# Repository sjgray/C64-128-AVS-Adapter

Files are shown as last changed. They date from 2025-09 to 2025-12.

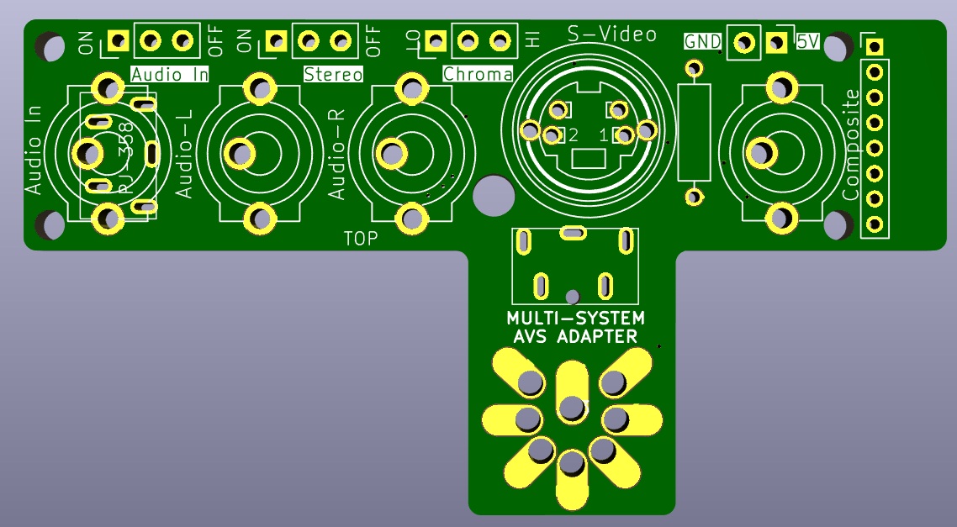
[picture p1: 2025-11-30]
V2/Pics/Render-front.jpg

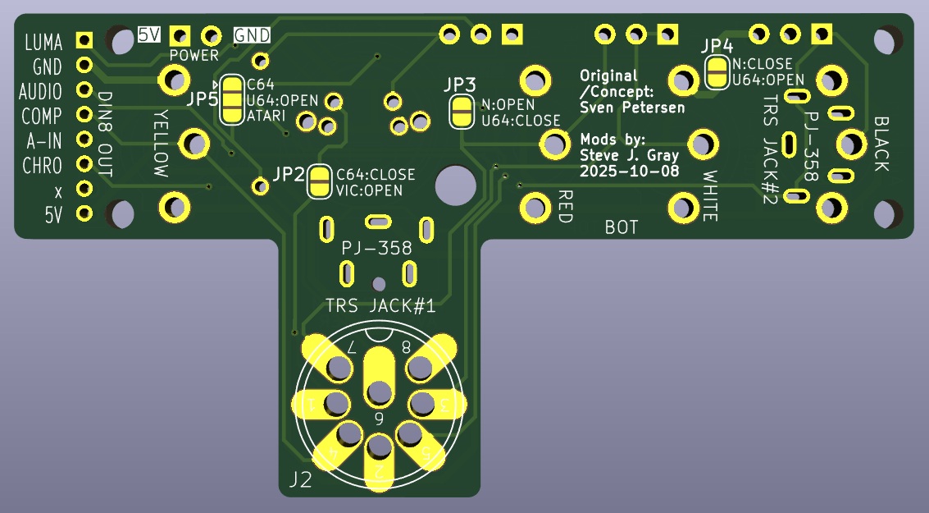
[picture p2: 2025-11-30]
V2/Pics/Render-back.jpg

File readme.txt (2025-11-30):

C64/C128 and Multi-System AVS Boards  by Steve J. Gray,  WWW.CBMSTEVE.CA
====================================

These are Commodore C64/C128 and Multi-System adapter boards based on
designs by Sven Petersen (https://github.com/svenpetersen1965?tab=repositories)
Sven has several designs for C64, C128 and VIC-20. These are separate boards
due to different DIN connectors, placement, and pinout differences. Also the
boards were designed with Eagle CAD.

My idea was first to combine the C64 and C128 boards into one by re-arranging
the RCA and S-VIDEO connectors to place them all at the top and hence allowing
the board to work on either machine. This is my "C64/C128" version.

The second idea was to make a board that could be configurable for different
systems. I added various solder-pad jumpers and added VIC-20, VIC-20 S-Video,
and Atari 8-bit configurations. This is the "Multi-System AVS" version.

Since I use Kicad I initially imported Sven's designs to get the proper part
footprints, and then working from there pretty much re-designed everything
for the new form factor(s) and options. I also added options for TRS connector
jacks for the Audio In, a connector for power output, and PH2.0 connector for
an additional video link cable to my C128 VGA15kHz+S-VIDEO 40/80 adapter
board (coming soon).

Designs
=======

V1:	- "C64/C128 AVS", for late model C64, 64C, C128, C16, SX-64 etc with DIN-8 video port.
	- Relocated connectors.
	- Power connector for +5V.
	- Made all jumpers 3-pin for headers or small switches (2.54mm spacing).
	- Not suitable for 3D printed case due to clearance issue.
	- Verified working.

V2:	- Now "Multi-System AVS".
	- Add support for VIC-20 (DIN-5)
	- Add support VIC-20 with Retro-Channel S-video adapter board (DIN-5).
	- Add support for Atari 8-bit (DIN-5) and chroma output.
	- Add support for U64 (DIN-8).
	- Move switches to top for easier access.
	- Add more clearance above DIN connector. Good for 3D case (Future).
	- Add TRS jacks for audio in.
	- Add header for cable to my C128 video adapter board.
	- Verified working.

GitHub
======

Designs are available here: https://github.com/sjgray/C64-128-AVS-Adapter

History
=======

2025-09-13 - Created C64/C128-AVS adapter
2025-09-22 - Created Github
2025-10-08 - Created Multi-System AVS completed
2025-11-29 - Tested ok, released V2 to Github

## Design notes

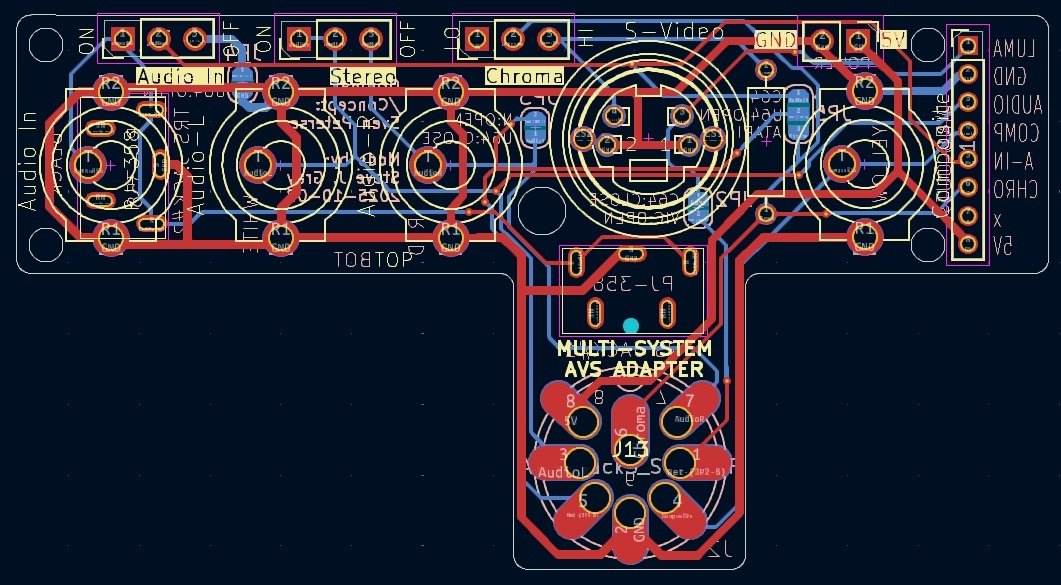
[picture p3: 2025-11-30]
V2/Pics/Routing.jpg

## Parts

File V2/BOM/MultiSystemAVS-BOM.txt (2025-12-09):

Multi-System AVS Adapter board - BOM
====================================

Mini Switches angled:	https://www.aliexpress.com/item/1005009818573388.html
Mini Switches straight:	https://www.aliexpress.com/item/1005007162182882.html
Audio TRS jacks:	https://www.aliexpress.com/item/1005001463775655.html
5-pin DIN male:		https://www.aliexpress.com/item/1005009672096638.html
8-pin DIN male:		https://www.aliexpress.com/item/1005002071264550.html
4-pin S-VIDEO:		https://www.aliexpress.com/item/1005005377343340.html   (choose 4 pin!)
RCA jack (multi color): https://www.aliexpress.com/item/1005008112895064.html

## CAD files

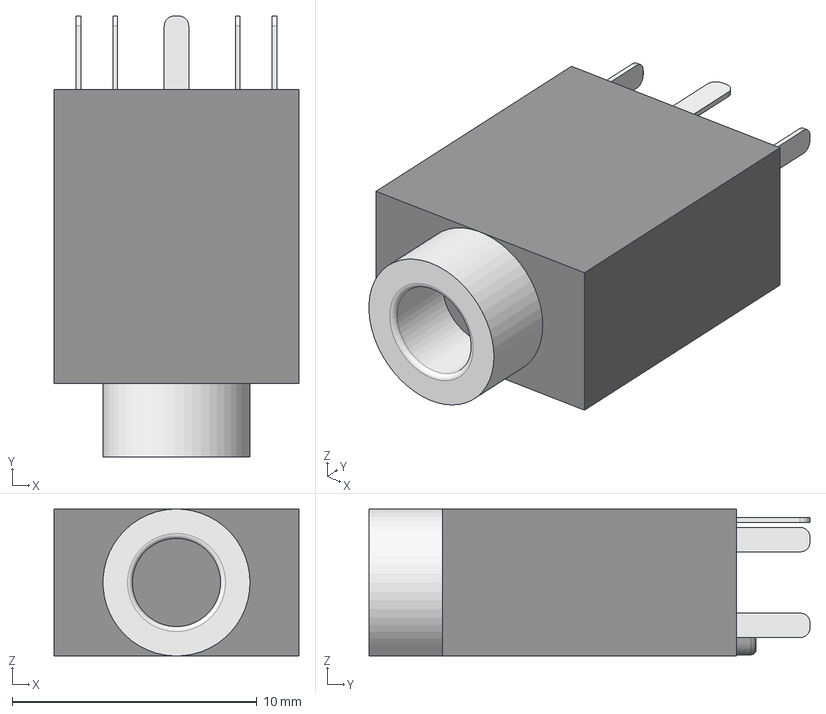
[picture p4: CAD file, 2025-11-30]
V2/3d-models/PJ358.step
10.0 x 18.0 x 6.00 mm
Brass
Pin02 x 5

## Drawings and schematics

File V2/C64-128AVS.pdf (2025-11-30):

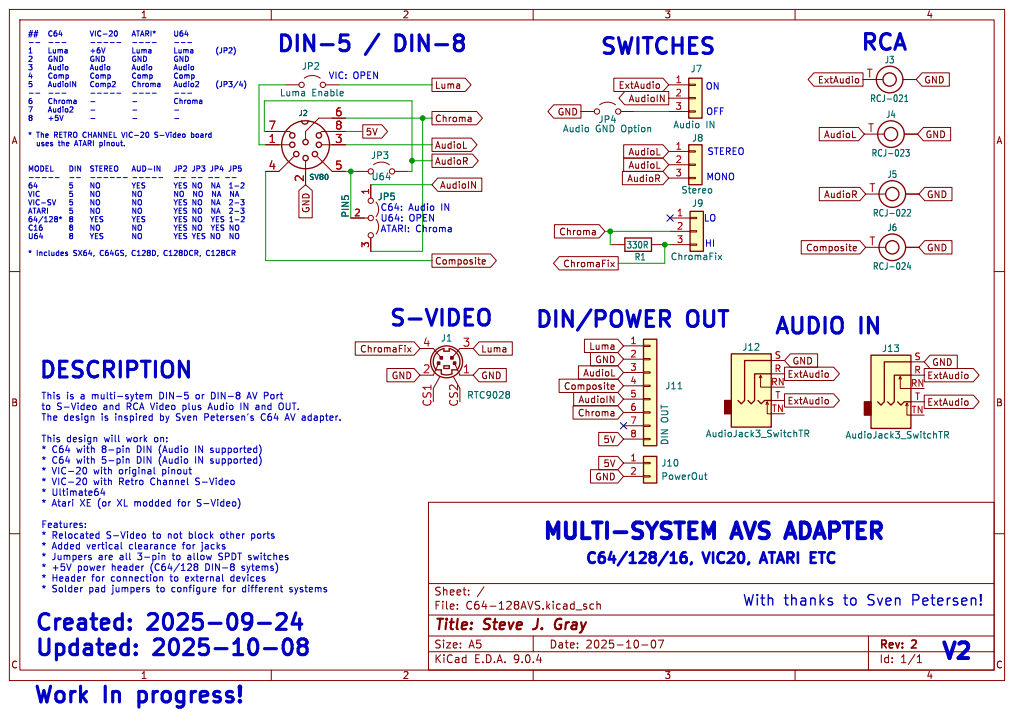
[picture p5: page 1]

## C64 VIC-20 ATARI* U64
-- --- ----- ---- --- 1 Luma +6V Luma Luma (JP2) 2 GND GND GND GND
4 Comp Comp Comp Comp
5 AudioIN Comp2 Chroma Audio2 (JP3/4)
-- --- ----- ---- --- 6 Chroma - - Chroma

3 Audio Audio Audio Audio

AudioL AudioL GND
JP4 Audio GND Option
STEREO DIN/POWER OUT

With thanks to Sven Petersen!

Id: 1/1 Title: Steve J. Gray

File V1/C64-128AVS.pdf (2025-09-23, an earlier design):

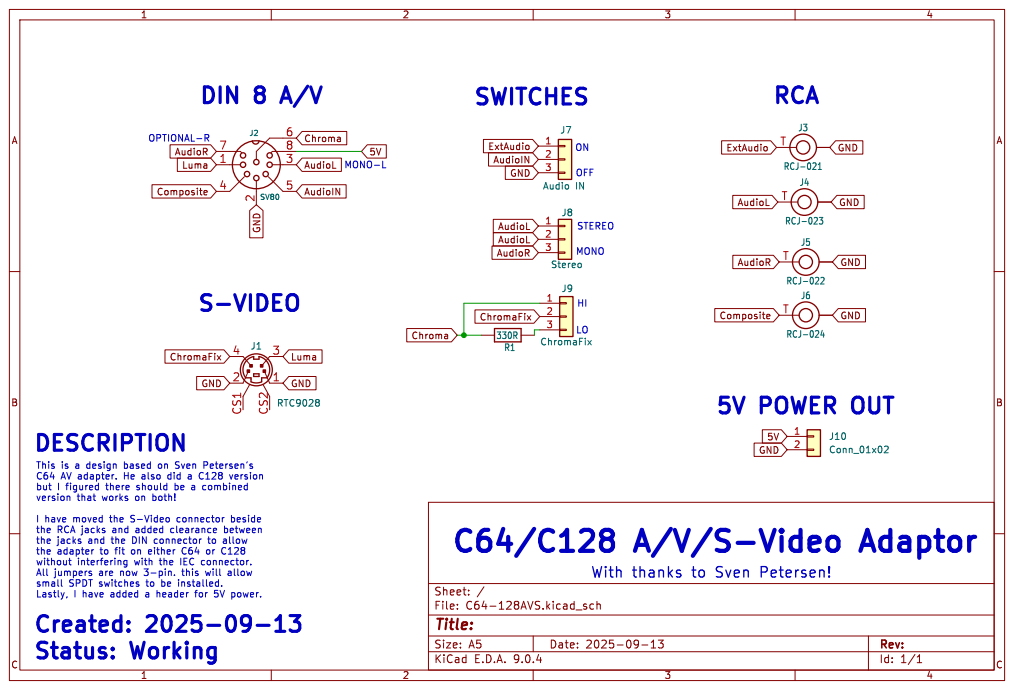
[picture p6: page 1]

small SPDT switches to be installed. Lastly, I have added a header for 5V power. DESCRIPTION

but I figured there should be a combined
version that works on both!

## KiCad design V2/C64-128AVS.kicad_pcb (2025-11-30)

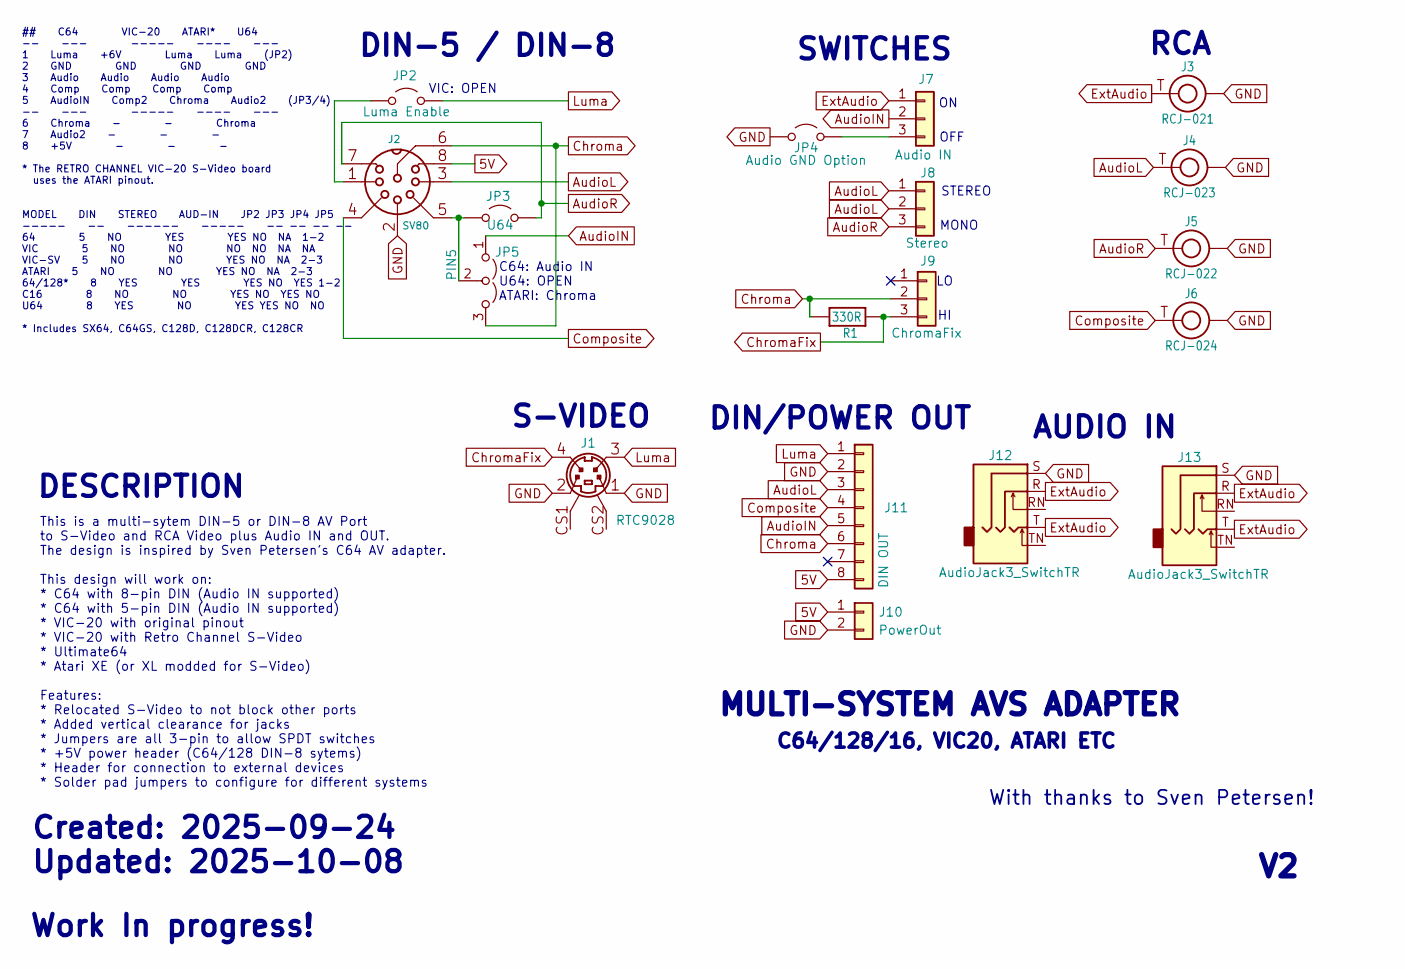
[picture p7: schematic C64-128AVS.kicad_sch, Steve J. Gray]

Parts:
J1: RTC9028; MINIDIN4_V
J2: SV80; SV80_INNER
J3: RCJ-021; RCJ-02X
J4: RCJ-023; RCJ-02X
J5: RCJ-022; RCJ-02X
J6: RCJ-024; RCJ-02X
J7: Audio IN; PinHeader_1x03_P2.54mm_Vertical
J8: Stereo; PinHeader_1x03_P2.54mm_Vertical
J9: ChromaFix; PinHeader_1x03_P2.54mm_Vertical
J10: PowerOut; PinHeader_1x02_P2.54mm_Vertical
J11: DIN OUT; PinHeader_1x08_P2.00mm_Vertical
J12, J13: AudioJack3_SwitchTR; Jack_3.5mm_CUI_PJ-358_vertical
JP2: Luma Enable; SolderJumper-2_P1.3mm_Open_RoundedPad1.0x1.5mm
JP3: U64; SolderJumper-2_P1.3mm_Open_RoundedPad1.0x1.5mm
JP4: Audio GND Option; SolderJumper-2_P1.3mm_Open_RoundedPad1.0x1.5mm
JP5: PIN5; SolderJumper-3_P1.3mm_Open_RoundedPad1.0x1.5mm
R1: 330R; R-10

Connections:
5V: J2.8, J10.1, J11.8
AudioIN: J7.2, J11.5, JP5.1 (A)
AudioL: J2.3, J4.T, J8.1, J8.2, J11.3
AudioR: J2.7, J5.T, J8.3, JP3.1 (A)
Chroma: J2.6, J9.2, J11.6, JP5.3 (B), R1.1
ChromaFix: J1.4, J9.3, R1.2
Composite: J2.4, J6.T, J11.4
ExtAudio: J3.T, J7.1, J12.R, J12.T, J13.R, J13.T
GND: J1.1, J1.2, J2.2, J3.R1 (R), J3.R2 (R), J4.R1 (R), J4.R2 (R), J5.R1 (R), J5.R2 (R), J6.R1 (R), J6.R2 (R), J10.2, J11.2, J12.S, J13.S, JP4.2 (B)
Luma: J1.3, J11.1, JP2.1 (A)
unnamed: J7.3, JP4.1 (A)
unnamed: J2.1, JP2.2 (B)
unnamed: J2.5, JP3.2 (B), JP5.2 (C)

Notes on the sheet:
VIC: OPEN
Work In progress!
MULTI-SYSTEM AVS ADAPTER
This is a multi-sytem DIN-5 or DIN-8 AV Port to S-Video and RCA Video plus Audio IN and OUT. The design is inspired by Sven Petersen's C64 AV adapter. This design will work on: * C64 with 8-pin DIN (Audio IN supported) * C64 with 5-pin DIN (Audio IN supported) * VIC-20 with original pinout * VIC-20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
MONO
OFF
C64/128/16, VIC20, ATARI ETC
DIN/POWER OUT
RCA
SWITCHES
DIN-5 / DIN-8
Created: 2025-09-24 Updated: 2025-10-08
STEREO
AUDIO IN
C64: Audio IN U64: OPEN ATARI: Chroma
## C64 VIC-20 ATARI* U64 -- --- ----- ---- --- 1 Luma +6V Luma Luma (JP2) 2 GND GND GND GND 3 Audio Audio Audio Audio 4 Comp Comp Comp Comp 5 AudioIN Comp2 Chroma Audio2 (JP3/4) -- --- ----- ---- --- 6 Chroma - - Chroma 7 Audio2 - - - 8 +5V - - - * The RETRO CHANNEL VIC-20 S-Video board uses the AT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
With thanks to Sven Petersen!
DESCRIPTION
S-VIDEO

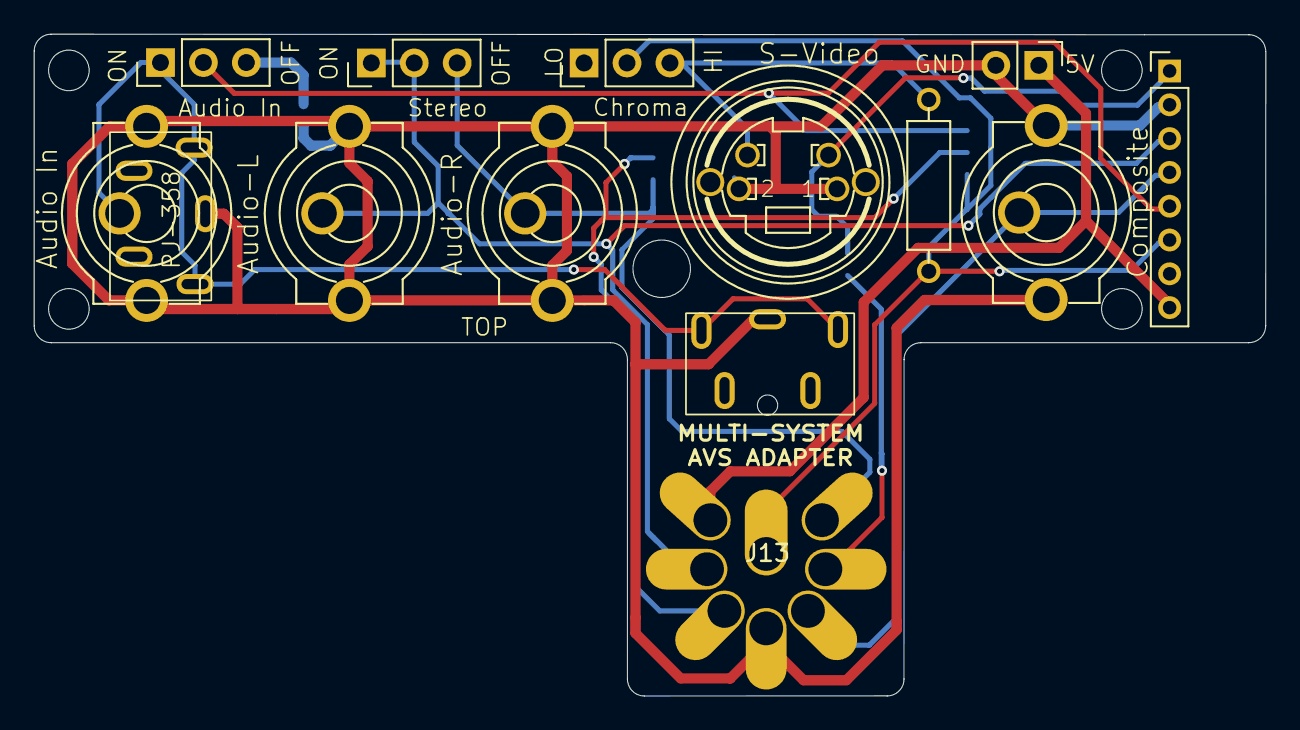
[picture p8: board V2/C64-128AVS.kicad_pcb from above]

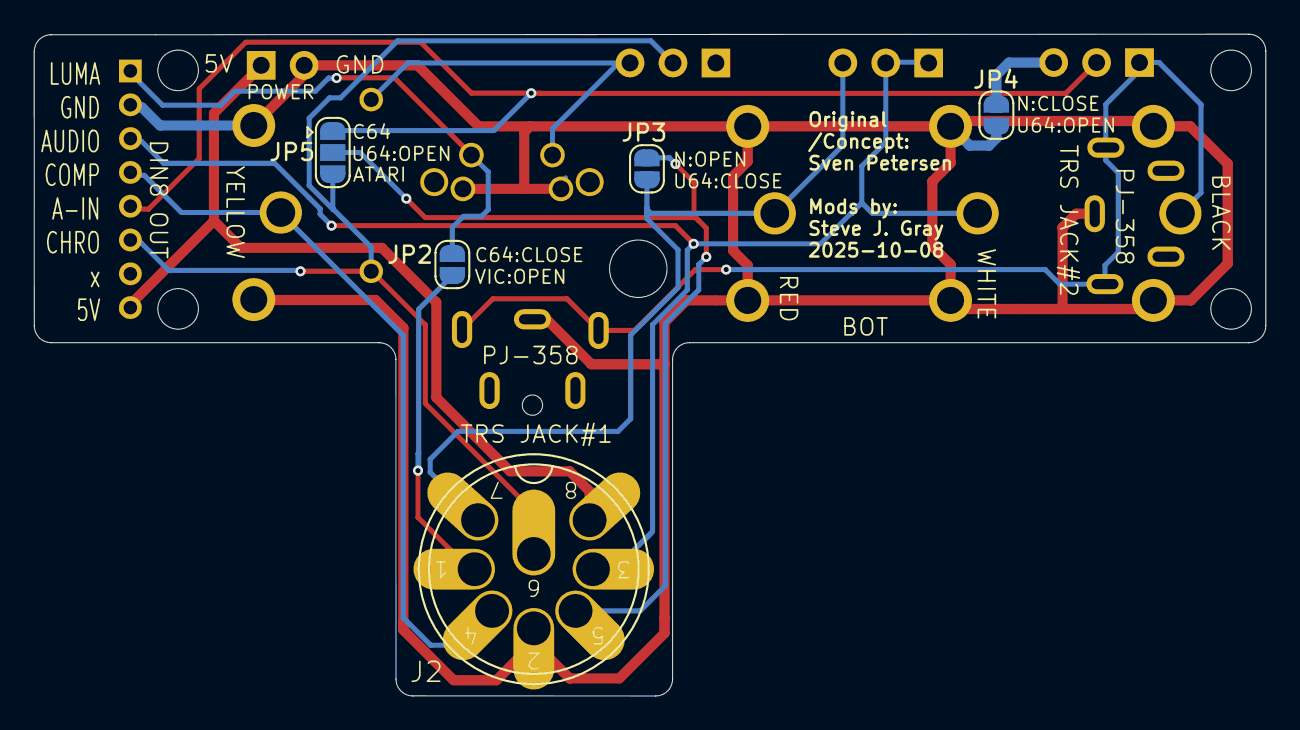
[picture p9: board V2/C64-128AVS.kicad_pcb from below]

Board: 2 copper layers, 72.9 x 39.2 mm, 18 parts (5 on the bottom side), 13 nets.

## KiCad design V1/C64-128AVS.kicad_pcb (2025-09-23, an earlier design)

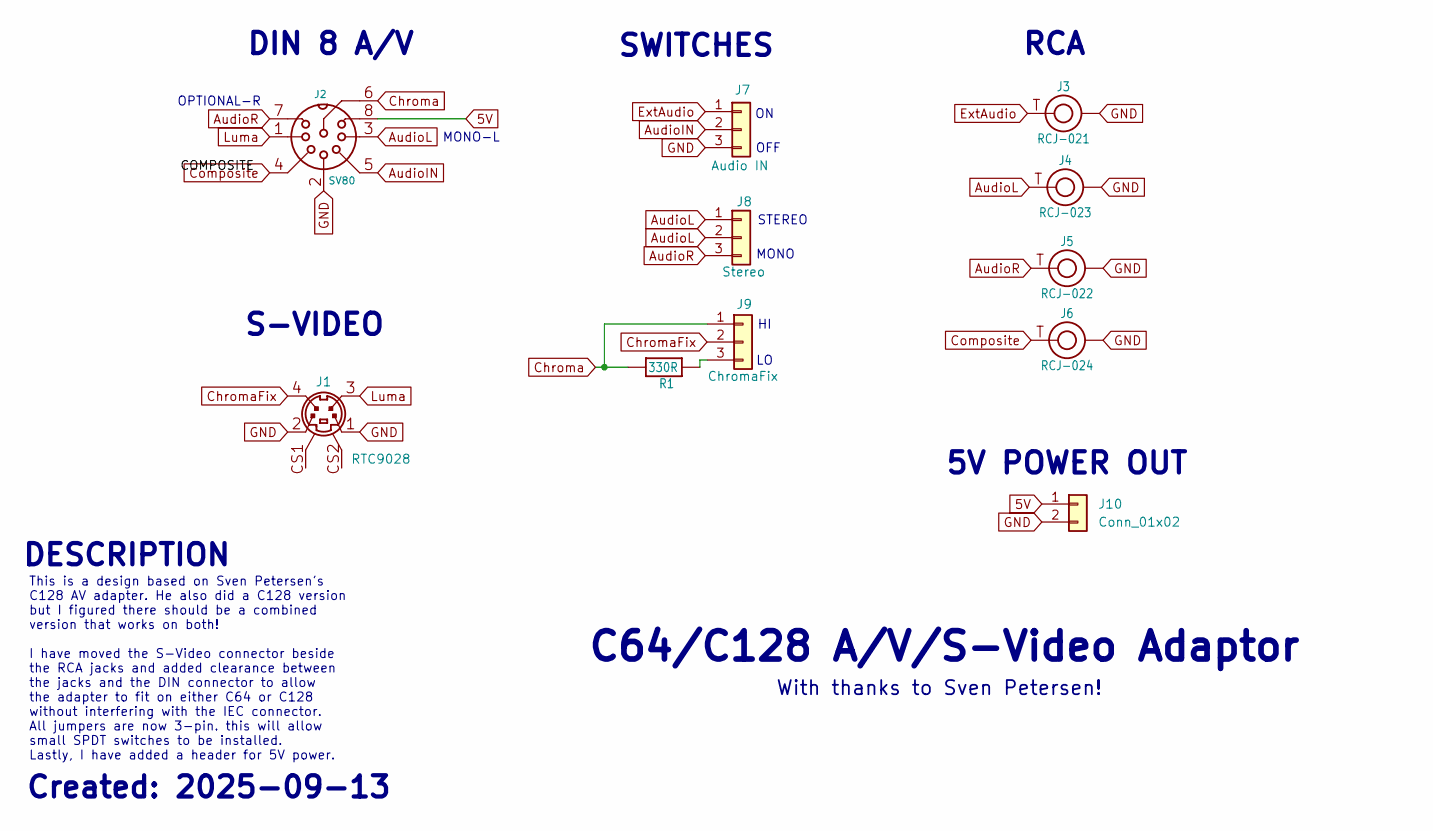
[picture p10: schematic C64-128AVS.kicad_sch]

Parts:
J1: RTC9028; MINIDIN4_V
J2: SV80; SV80_INNER
J3: RCJ-021; RCJ-02X
J4: RCJ-023; RCJ-02X
J5: RCJ-022; RCJ-02X
J6: RCJ-024; RCJ-02X
J7: Audio IN; PinHeader_1x03_P2.54mm_Vertical
J8: Stereo; PinHeader_1x03_P2.54mm_Vertical
J9: ChromaFix; PinHeader_1x03_P2.54mm_Vertical
J10: Conn_01x02; PinHeader_1x02_P2.54mm_Vertical
R1: 330R; R-10

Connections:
5V: J2.8, J10.1
AudioIN: J2.5, J7.2
AudioL: J2.3, J4.T, J8.1, J8.2
AudioR: J2.7, J5.T, J8.3
Chroma: J2.6, J9.1, R1.1
ChromaFix: J1.4, J9.2
Composite: J2.4, J6.T
ExtAudio: J3.T, J7.1
GND: J1.1, J1.2, J2.2, J3.R1 (R), J3.R2 (R), J4.R1 (R), J4.R2 (R), J5.R1 (R), J5.R2 (R), J6.R1 (R), J6.R2 (R), J7.3, J10.2
Luma: J1.3, J2.1
unnamed: J9.3, R1.2

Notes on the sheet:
OPTIONAL-R
C64/C128 A/V/S-Video Adaptor
This is a design based on Sven Petersen's C128 AV adapter. He also did a C128 version but I figured there should be a combined version that works on both! I have moved the S-Video connector beside the RCA jacks and added clearance between the jacks and the DIN connector to allow the adapter to fit 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
MONO
5V POWER OUT
OFF
RCA
MONO-L
SWITCHES
DIN 8 A/V
Created: 2025-09-13
STEREO
With thanks to Sven Petersen!
DESCRIPTION
S-VIDEO

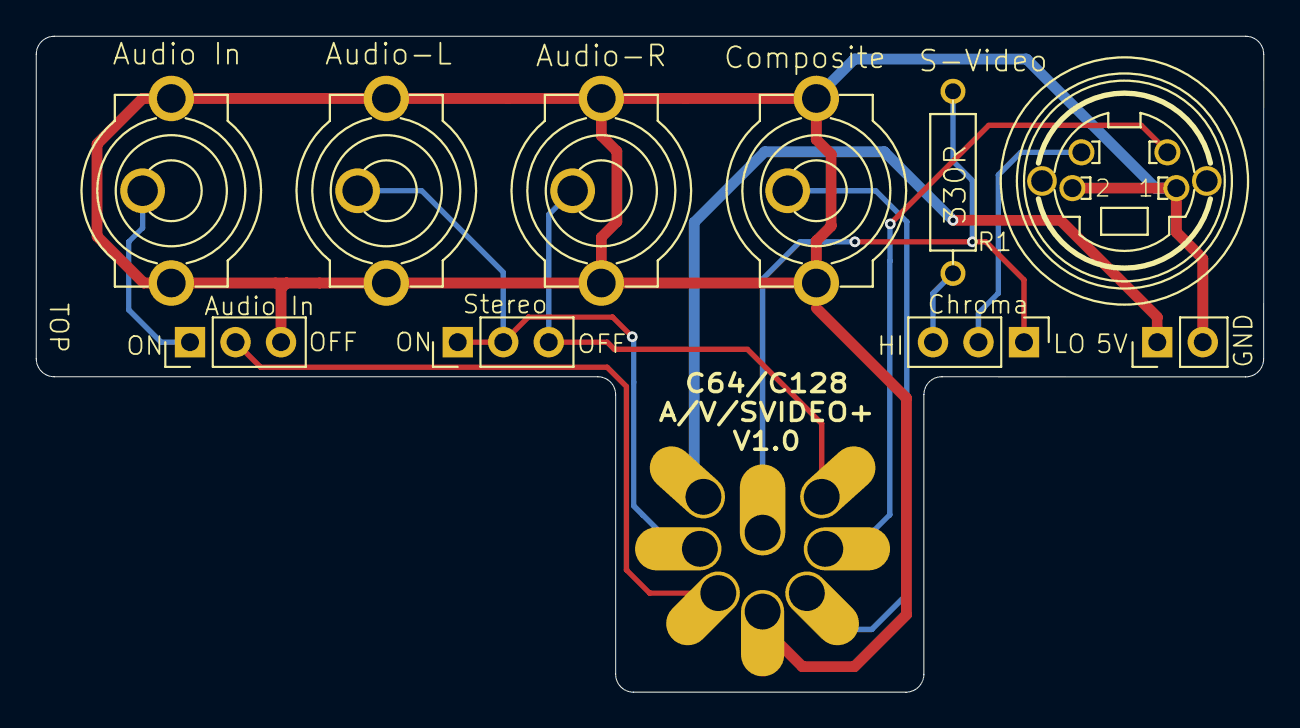
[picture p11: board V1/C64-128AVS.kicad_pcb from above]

Board: 2 copper layers, 68.5 x 36.6 mm, 11 parts (1 on the bottom side), 11 nets.

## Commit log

2025-09-23 V1 release
    Thanks to Sven Petersen for the initial C64 design. Converted to Kicad and modified to work on both C64 and C128. C64 must be 8-pin DIN. Note some C64 do not supply power but can be fixed with a small mod.
    [C64-128AVS-B_Cu.gbr, C64-128AVS-B_Mask.gbr, C64-128AVS-B_Paste.gbr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]
2025-09-23 Update schematic and add BOM
    Updated schematic to add working status. Add interactive BOM.
    [C64-128AVS.kicad_sch]
2025-11-30 Add V2 "Multi-System AVS" board
    Fix clearance, add support for VIC-20, VIC-20 S-Video, and Atari 8-bit systems with DIN-5. Add support for U64. Add TRS audio jacks, configuration jumpers and 8-pin signal header. Move switches to the top.
    [C64-128AVS-B_Cu.gbr, C64-128AVS-B_Mask.gbr, C64-128AVS-B_Paste.gbr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]
2025-12-09 Add V2 BOM
    I sourced all my parts from AliExpress except common parts like headers, resistors etc.
2025-12-10 Add V2 Interactive BOM
    Add V2 Interactive BOM.
